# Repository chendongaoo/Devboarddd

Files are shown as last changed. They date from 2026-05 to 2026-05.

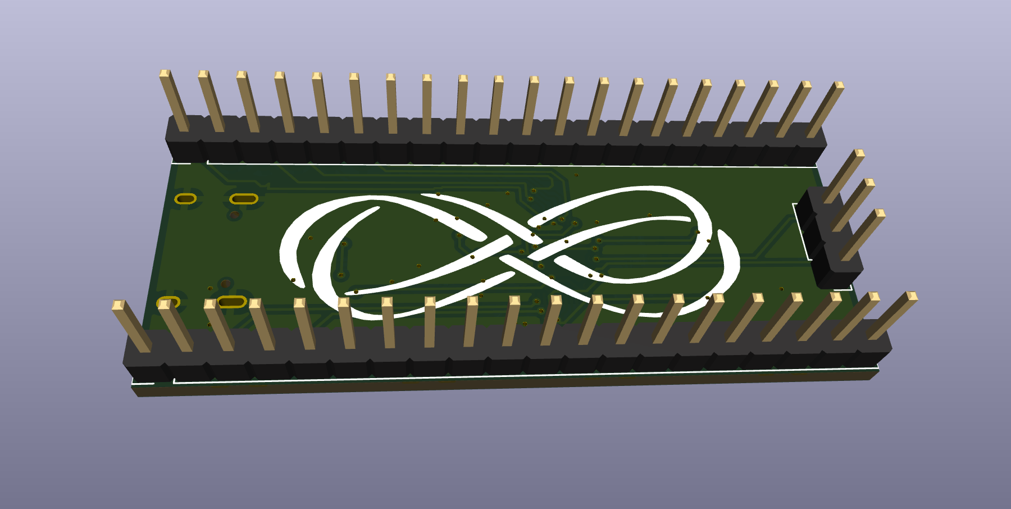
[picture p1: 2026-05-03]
PCB/Pictures/Back.png

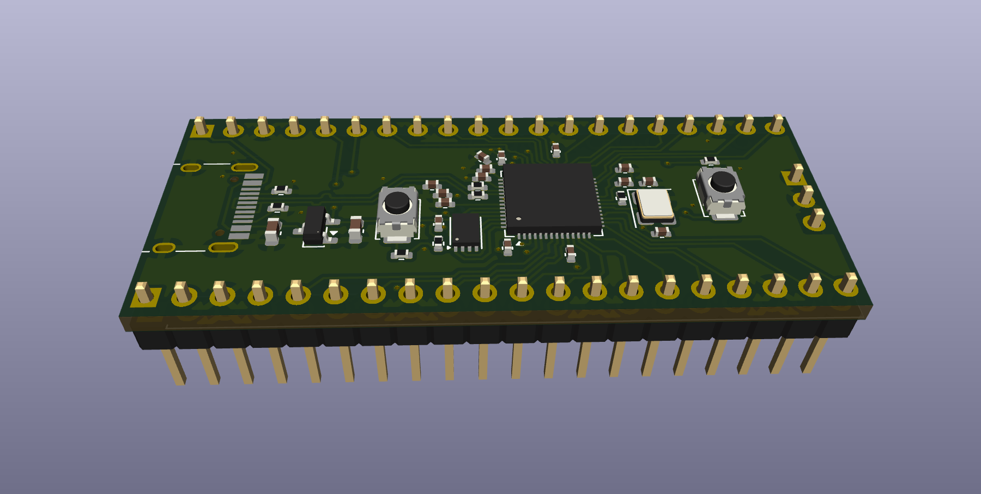
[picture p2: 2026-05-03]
PCB/Pictures/Front.png

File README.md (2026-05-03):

# Devboarddd
A custom devboard made and designed by myself for the first time!

Probably one of the hardest projects I ever worked on, especially because I had no idea what to expect going in but everything was worthwhile. I learned lots of information from working on this devboard.

# PCB
This was all done on an application called KiCAD

- Schematic
- Schematic
- PCB
- PCB

# 3D Design/Model
By using the 3d viewer on KiCAD I was able to get a visualization of what the devboard would look like in the real world.

- Front
- Front
- Back
- Back

# BOM (Bill of Materials)
| Quantity | Comment | Designator | Footprint | Link |
|---|---|---|---|---|
| 11 | 0.1uF | C2-9, C11, C12, C17 | C_0402_1005Metric | https://www.lcsc.com/product-detail/C1525.html |
| 2 | 5.1K | R1, R2 | R_0402_1005Metric | https://www.lcsc.com/product-detail/C25905.html |
| 2 | 10uF | C13, C14 | C_0603_1608Metric | https://www.lcsc.com/product-detail/C19702.html |
| 2 | 33pF | C15, C16 | C_0402_1005Metric | https://www.lcsc.com/product-detail/C107047.html |
| 2 | 1K | R5, R7 | R_0402_1005Metric | https://www.lcsc.com/product-detail/C11702.html |
| 2 | 10K | R6, R8 | R_0402_1005Metric | https://www.lcsc.com/product-detail/C60490.html |
| 2 | 27 | R3, R4 | R_0402_1005Metric | https://www.lcsc.com/product-detail/C25100.html |
| 2 | 1uF | C1, C10 | C_0402_1005Metric | https://www.lcsc.com/product-detail/C29266.html |
| 2 | Conn_01x20 | J2, J3 | PinHeader_1x20_P2.54mm_Vertical | https://www.lcsc.com/product-detail/C42431804.html |
| 1 | Conn_01x03 | J4 | PinHeader_1x03_P2.54mm_Vertical | https://www.lcsc.com/product-detail/C32713269.html |
| 1 | SW_Push | SW1, SW2 | SW_Push_SPST_NO_Alps_SKRK | https://www.lcsc.com/product-detail/C720477.html |
| 1 | W25Q128JVS | U3 | Winbond_USON-8-1EP_3x2mm_P0.5mm_EP0.2x1.6mm | https://www.lcsc.com/product-detail/C2456208.html  |
| 1 | MCP1700x-330xxTT | U4 | SOT-23 | https://www.lcsc.com/product-detail/C39051.html |
| 1 | 12MHz | Y1 | Crystal_SMD_3225-4Pin_3.2x2.5mm | https://www.lcsc.com/product-detail/C9002.html |
| 1 | USB_C_Receptacle_USB2.0_14P | J1 | USB_C_Receptacle_HRO_TYPE-C-31-M-12 | https://www.lcsc.com/product-detail/C165948.html |
| 1 | RP2040 | U1 | QFN-56-1EP_7x7mm_P0.4mm_EP3.2x3.2mm | https://www.lcsc.com/product-detail/C2040.html |
| PCBA Estimated Price| $51.38

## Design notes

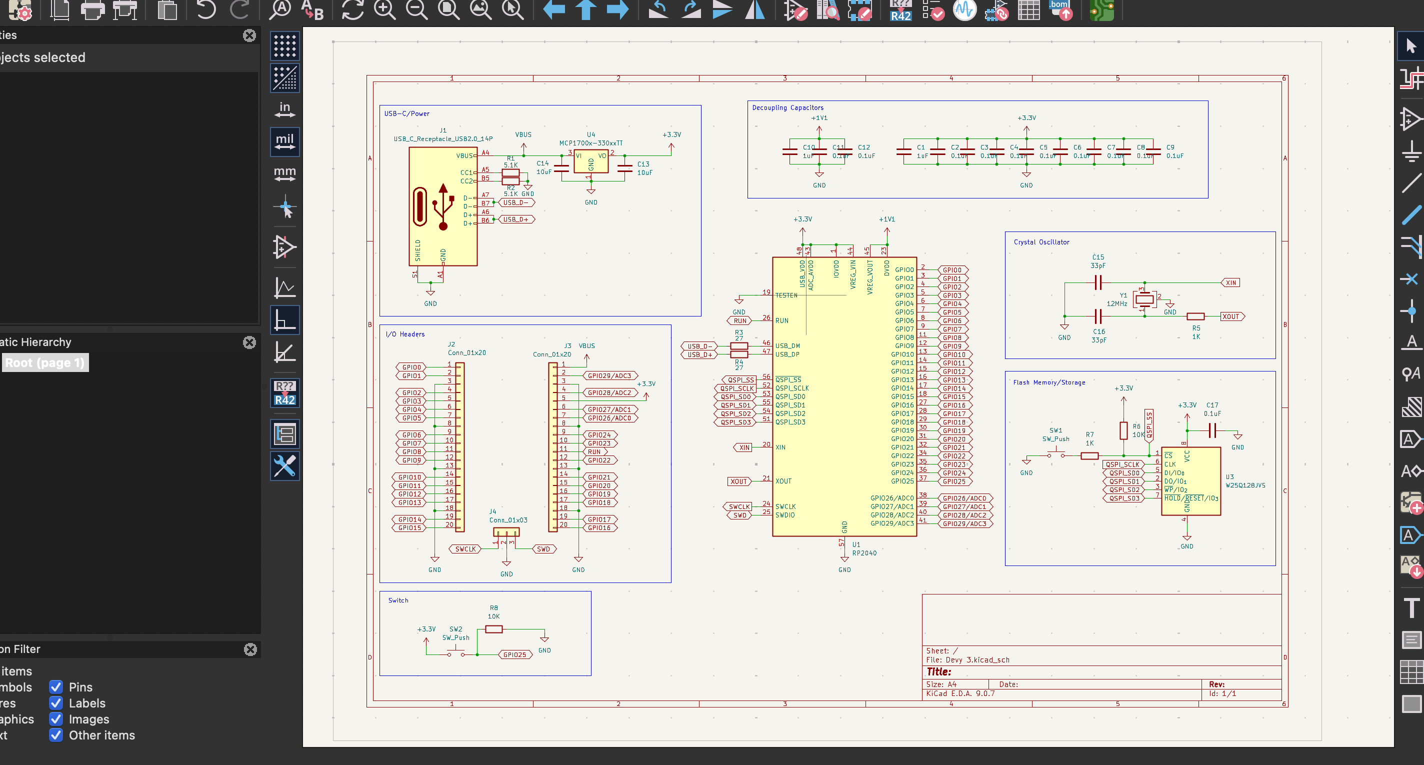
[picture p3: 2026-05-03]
PCB/Pictures/Schematic.png

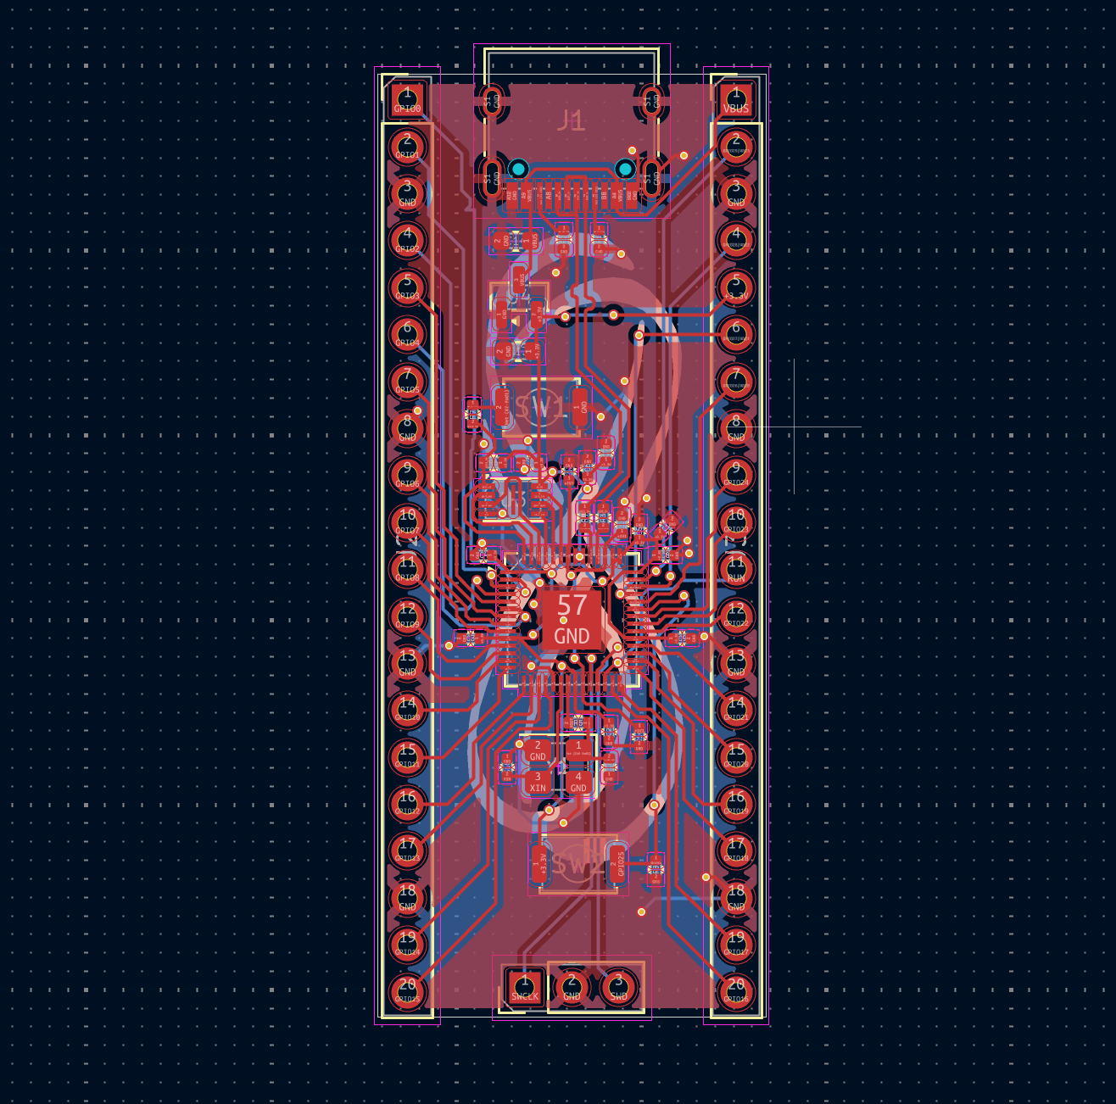
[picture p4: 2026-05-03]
PCB/Pictures/PCB.png

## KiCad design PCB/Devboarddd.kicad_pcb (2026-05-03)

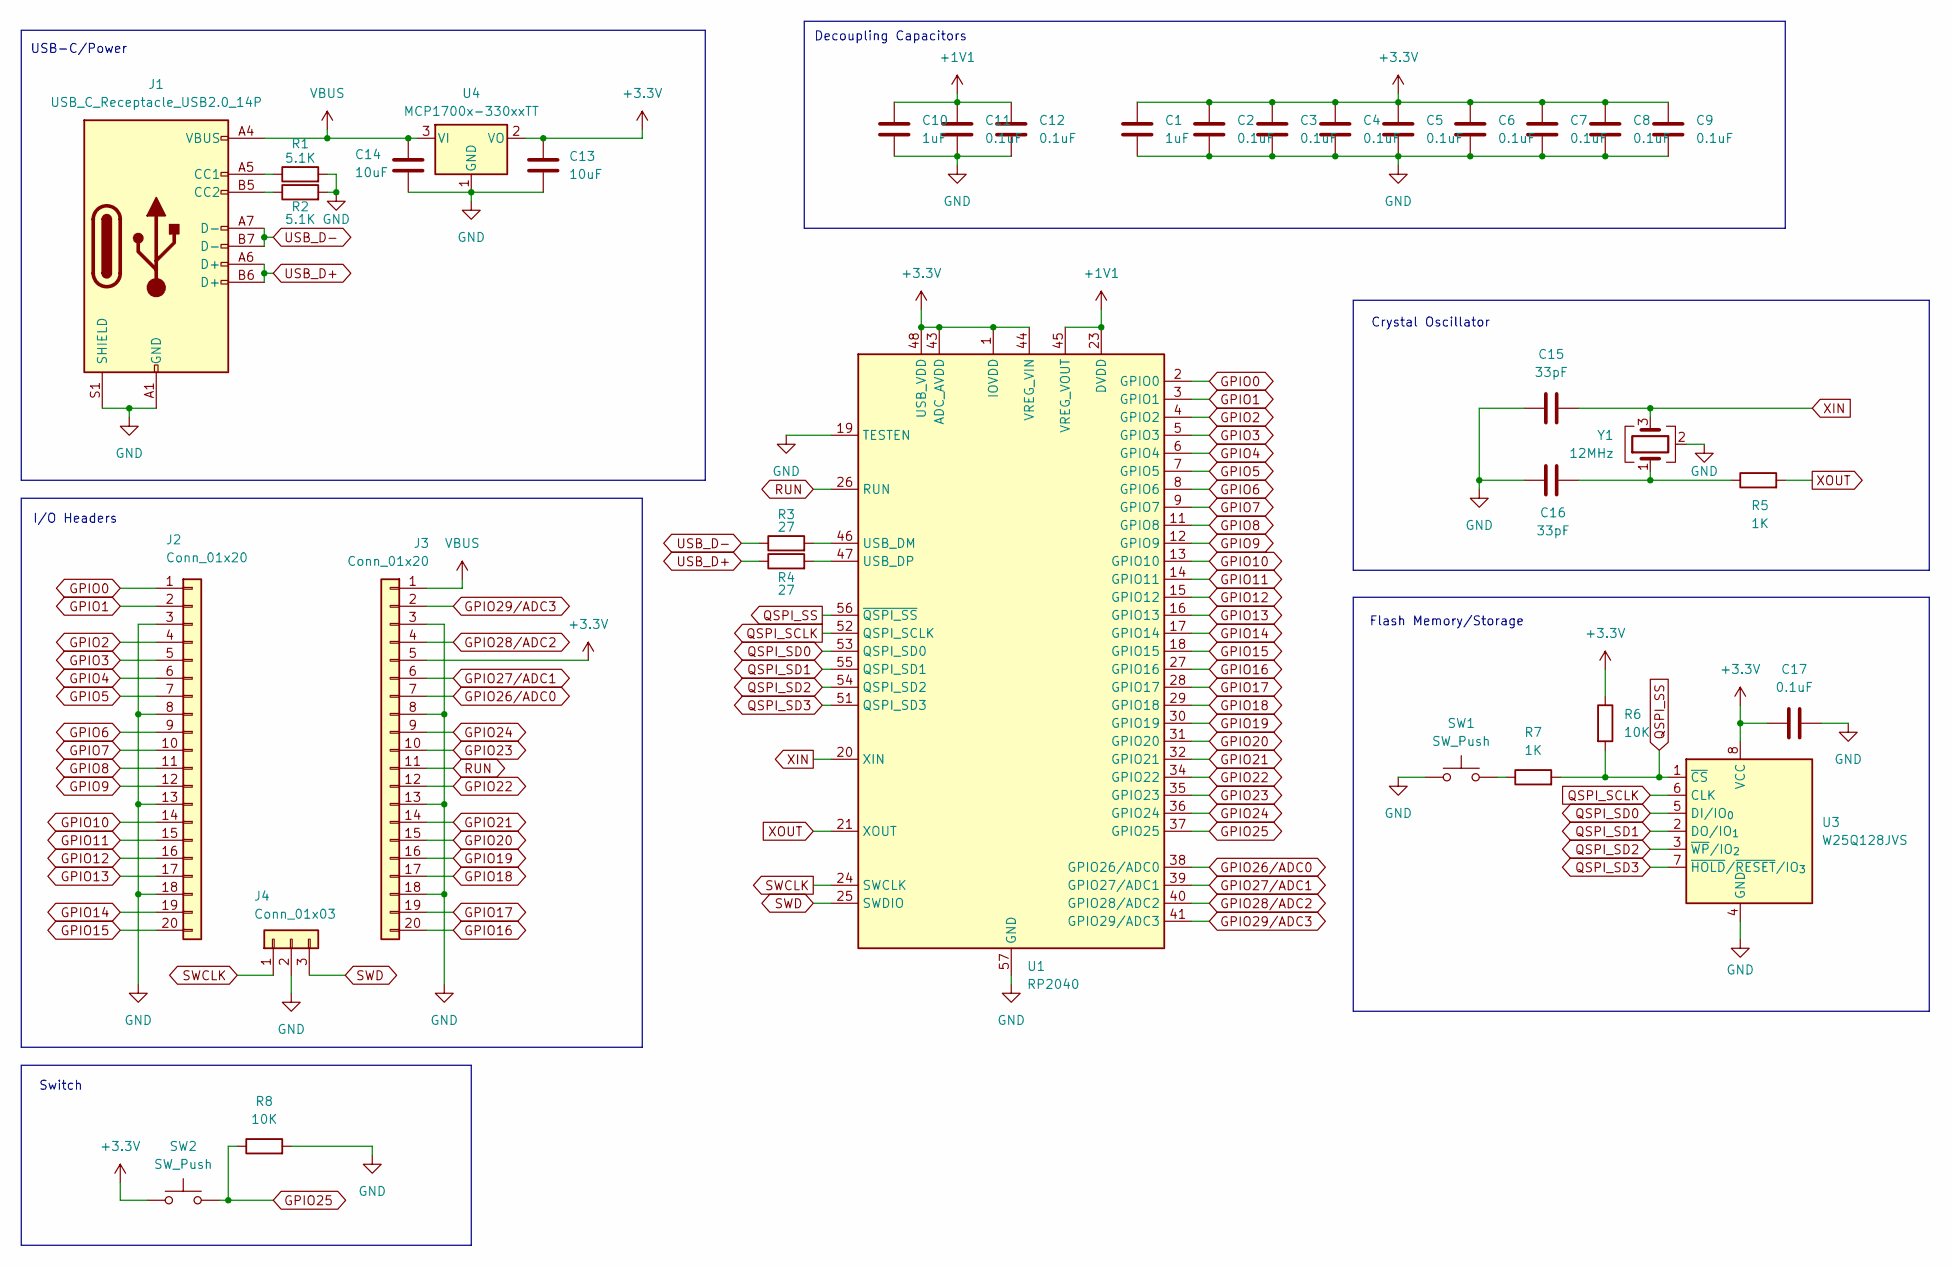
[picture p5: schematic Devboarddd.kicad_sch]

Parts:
C1, C10: 1uF; C_0402_1005Metric
C2, C3, C4, C5, C6, C7, C8, C9, C11, C12, C17: 0.1uF; C_0402_1005Metric
C13, C14: 10uF; C_0603_1608Metric
C15, C16: 33pF; C_0402_1005Metric
J1: USB_C_Receptacle_USB2.0_14P; USB_C_Receptacle_HRO_TYPE-C-31-M-12
J2, J3: Conn_01x20; PinHeader_1x20_P2.54mm_Vertical
J4: Conn_01x03; PinHeader_1x03_P2.54mm_Vertical
R1, R2: 5.1K; R_0402_1005Metric
R3, R4: 27; R_0402_1005Metric
R5, R7: 1K; R_0402_1005Metric
R6, R8: 10K; R_0402_1005Metric
SW1, SW2: SW_Push; SW_Push_SPST_NO_Alps_SKRK
U1: RP2040; QFN-56-1EP_7x7mm_P0.4mm_EP3.2x3.2mm
U3: W25Q128JVS; Winbond_USON-8-1EP_3x2mm_P0.5mm_EP0.2x1.6mm
U4: MCP1700x-330xxTT; SOT-23
Y1: 12MHz; Crystal_SMD_3225-4Pin_3.2x2.5mm

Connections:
+1V1: C10.1, C11.1, C12.1, U1.23 (DVDD), U1.45 (VREG_VOUT), U1.50 (DVDD)
+3.3V: C1.1, C2.1, C3.1, C4.1, C5.1, C6.1, C7.1, C8.1, C9.1, C13.1, C17.1, J3.5, R6.1, SW2.1, U1.1 (IOVDD), U1.10 (IOVDD), U1.22 (IOVDD), U1.33 (IOVDD), U1.42 (IOVDD), U1.43 (ADC_AVDD), U1.44 (VREG_VIN), U1.48 (USB_VDD), U1.49 (IOVDD), U3.8 (VCC), U4.2 (VO)
GND: C1.2, C2.2, C3.2, C4.2, C5.2, C6.2, C7.2, C8.2, C9.2, C10.2, C11.2, C12.2, C13.2, C14.2, C15.1, C16.1, C17.2, J1.A1 (GND), J1.A12 (GND), J1.B1 (GND), J1.B12 (GND), J1.S1 (SHIELD), J2.3, J2.8, J2.13, J2.18, J3.3, J3.8, J3.13, J3.18, J4.2, R1.2, R2.2, R8.2, SW1.1, U1.19 (TESTEN), U1.57 (GND), U3.4 (GND), U4.1 (GND), Y1.2 (G), Y1.4 (G)
GPIO0: J2.1, U1.2 (GPIO0)
GPIO1: J2.2, U1.3 (GPIO1)
GPIO2: J2.4, U1.4 (GPIO2)
GPIO3: J2.5, U1.5 (GPIO3)
GPIO4: J2.6, U1.6 (GPIO4)
GPIO5: J2.7, U1.7 (GPIO5)
GPIO6: J2.9, U1.8 (GPIO6)
GPIO7: J2.10, U1.9 (GPIO7)
GPIO8: J2.11, U1.11 (GPIO8)
GPIO9: J2.12, U1.12 (GPIO9)
GPIO10: J2.14, U1.13 (GPIO10)
GPIO11: J2.15, U1.14 (GPIO11)
GPIO12: J2.16, U1.15 (GPIO12)
GPIO13: J2.17, U1.16 (GPIO13)
GPIO14: J2.19, U1.17 (GPIO14)
GPIO15: J2.20, U1.18 (GPIO15)
GPIO16: J3.20, U1.27 (GPIO16)
GPIO17: J3.19, U1.28 (GPIO17)
GPIO18: J3.17, U1.29 (GPIO18)
GPIO19: J3.16, U1.30 (GPIO19)
GPIO20: J3.15, U1.31 (GPIO20)
GPIO21: J3.14, U1.32 (GPIO21)
GPIO22: J3.12, U1.34 (GPIO22)
GPIO23: J3.10, U1.35 (GPIO23)
GPIO24: J3.9, U1.36 (GPIO24)
GPIO25: R8.1, SW2.2, U1.37 (GPIO25)
GPIO26/ADC0: J3.7, U1.38 (GPIO26/ADC0)
GPIO27/ADC1: J3.6, U1.39 (GPIO27/ADC1)
GPIO28/ADC2: J3.4, U1.40 (GPIO28/ADC2)
GPIO29/ADC3: J3.2, U1.41 (GPIO29/ADC3)
unnamed: C16.2, R5.1, Y1.1
unnamed: J1.A5 (CC1), R1.1
unnamed: J1.B5 (CC2), R2.1
unnamed: R7.1, SW1.2
unnamed: R3.2, U1.46 (USB_DM)
unnamed: R4.2, U1.47 (USB_DP)
QSPI_SCLK: U1.52 (QSPI_SCLK), U3.6 (CLK)
QSPI_SD0: U1.53 (QSPI_SD0), U3.5 (DI/IO_{0})
QSPI_SD1: U1.55 (QSPI_SD1), U3.2 (DO/IO_{1})
QSPI_SD2: U1.54 (QSPI_SD2), U3.3 (~WP/IO_{2})
QSPI_SD3: U1.51 (QSPI_SD3), U3.7 (~HOLD/~RESET/IO_{3})
QSPI_SS: R6.2, R7.2, U1.56 (~QSPI_SS), U3.1 (~CS)
RUN: J3.11, U1.26 (RUN)
SWCLK: J4.1, U1.24 (SWCLK)
SWD: J4.3, U1.25 (SWDIO)
USB_D+: J1.A6 (D+), J1.B6 (D+), R4.1
USB_D-: J1.A7 (D-), J1.B7 (D-), R3.1
VBUS: C14.1, J1.A4 (VBUS), J1.A9 (VBUS), J1.B4 (VBUS), J1.B9 (VBUS), J3.1, U4.3 (VI)
XIN: C15.2, U1.20 (XIN), Y1.3
XOUT: R5.2, U1.21 (XOUT)

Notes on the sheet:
Decoupling Capacitors
Switch
USB-C/Power
Crystal Oscillator
I/O Headers
Flash Memory/Storage

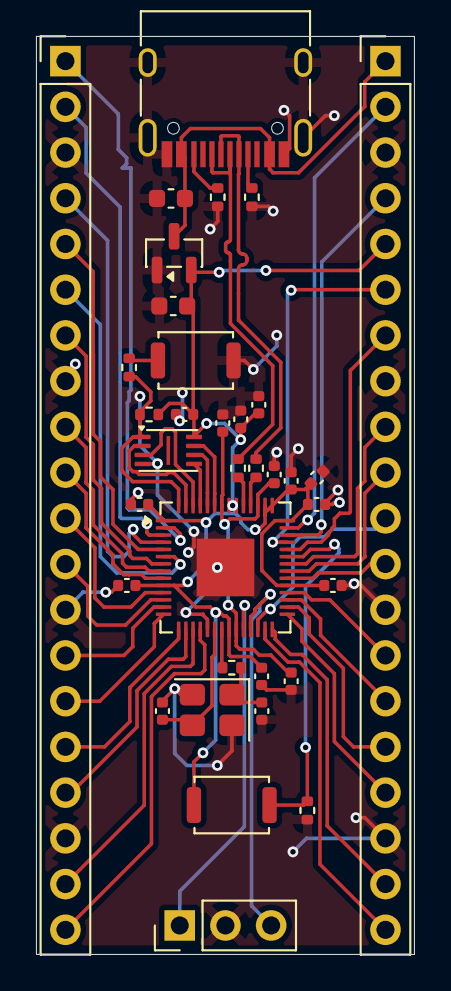
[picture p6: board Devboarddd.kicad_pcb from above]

Board: 2 copper layers, 21.0 x 51.0 mm, 35 parts (0 on the bottom side), 53 nets.

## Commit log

2026-05-03 uploaded corresponding files
    [BOM-Devboarddd.csv, Devboarddd.kicad_pcb, Devboarddd.kicad_sch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]
2026-05-03 organizing files
    [Devboarddd.kicad_pcb, Devboarddd.kicad_sch, DevboardddBOM.csv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]
2026-05-03 more organization
    [BOM-Devboarddd.csv, DevboardddBOM.csv]
